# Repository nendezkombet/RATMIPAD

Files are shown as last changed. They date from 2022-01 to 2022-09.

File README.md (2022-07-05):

# RATMIPAD

Ratmi is multi layout macropad supports six analog potentiometer, two rotary encoders, 3.5mm TRS socket for sending out serial data like midi output and more. The firmware is fully QMK, see [build environment setup](https://docs.qmk.fm/#/getting_started_build_tools) then the [make instructions](https://docs.qmk.fm/#/getting_started_make_guide) for more information. 
The analog potentiometer outputs a midi signal which can be recognized by any software reads midi input. For hardware midi controller the PCB has 3.5mm TRS female socket footprint ( 3.5mm TRS male jack to 5-pin midi midi cable as connector required ), for this specific purpose the programaing code can be done with arduinoIDE.

Designer and maintainer: [sandipratama/nendezkombet](https://github.com/nendezkombet) 





## Table of contents

- [Features](#features)
- [Default Layout](#default-layout)
- [Optional Layout](#optional-layout)
- [PCB](#pcb)
- [BOM](#bom)
- [Case](#case)
- [Assembly Guide](#assembly-guide)
- [Firmware](#firmware)

## Features

- Cheap to build.
- Multi layout support.
- Easy to source components.
- Easy to build.
- Arduino Pro Micro 32u4 as MCU.
- RGB backlighting support (optional).
- Up to two rotary encoder support.
- Hardware midi controller support.
- Battery powered support ( as portable controller ).
- Completely open-source.

## Default Layout



## Optional Layout 



From left to right layout configuration :

1. 1x big encoder knob with 6x key switch.
2. 9x key switch.
3. 2x small encoder knob with 7x key switch.
4. 1x big encoder knob with 6x analog potentiometer.

## PCB

Top view

upper

Bottom view

bottom

## BOM

|Parts|Footprint|Quantity|
|:---|:---|:---|
|WS2812B RGB LED |5050|8|
|100nF capacitor|0805|8|
|Cherry MX style switch |3 or 5 pin|9|
|Rotary encoder|EC11|2|
|Arduino Promicro |32u4|1|
|10K pullup resistor (optional)|0805 or axial|9|
|220ohm resistor|0805 or axial|3|
|Reset button switch |6mm*2.5mm|1|
|B10K Analog potentiometer (optional) | RV09 or RK09|6|
|3.5mm TRS female socket (optional) |PJ313|1|
|Micro slide switch (optional)|MSS22D18 |1|
|9V battery (optional) ||1|
|8mm M2 "MALE TO FEMALE" brass standoff|round knurled|4|
|8mm M2 "FEMALE TO FEMALE" brass standoff|round knurled|4|
|6mm M2 screw|-|8|
|3.5mm TRS jack to 5-pin midi din male socket (optional) |see detail below|1|

51kXivjBTuL _AC_SX425_

you can build by your self, wiring instruction can by found in the google search engine.

## Case

Stacked acrylic case 





## Assembly Guide

See inside "case" folder !!!

## Firmware

Firmware flashing :

Open QMK Toolbox and locate The .hex file you compiled before or use ready flash default keymap

Enter the bootloader :

Briefly press the button twice on the small hole located in the top of the encoder with simcard ejector pin than hit flash

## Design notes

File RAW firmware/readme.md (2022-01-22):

RATMIPAD

Ratmi is multi layout macropad supports six analog potentiometer, two rotary encoders, 3.5mm TRS socket for sending out serial data like midi output and more. The firmware is fully QMK. The analog potentiometer outputs a midi signal which can be recognized by any software reads midi input. For hardware midi controller the PCB has 3.5mm TRS female socket footprint ( 3.5mm TRS male jack to 5-pin midi midi cable as connector required ), for this specific purpose the programaing code can be done with arduinoIDE.

* Keyboard Maintainer: [sandipratama/nendezkombet](https://github.com/nendezkombet)
* Hardware Availability: https://github.com/nendezkombet/ratmipad

Make example for this keyboard (after setting up your build environment):

    make ratmipad:default

See the [build environment setup](https://docs.qmk.fm/#/getting_started_build_tools) and the [make instructions](https://docs.qmk.fm/#/getting_started_make_guide) for more information. Brand new to QMK? Start with our [Complete Newbs Guide](https://docs.qmk.fm/#/newbs).

Bootloader
Enter the bootloader :

Physical reset button: Briefly press the button two times on the small hole in the top of the encoder with simcard ejector pin

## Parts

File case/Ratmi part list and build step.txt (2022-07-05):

Macropad purpose :

1. 8x WS2812B RGB LEDs ( optional )
2. 8x SMD 0805 100nF capacitors ( this part just for prevent noise/flicker )
3. 6-9x Cherry MX style switch or kailh low provile V2 switch 
4. 1-2x EC11 rotary encoder ( optional )
5. 8x 6mm height M2 female
6. 4x 8mm height M2 female to male brass standoff ( knurled and round shape, hex shape will not work )
7. 4x 8mm height M2 female to female brass standoff ( knurled and round shape, hex shape will not work )
8. 1x Arduino Promicro 32u4 5v
9. 1x 220ohm or 330ohm resistor for RGB data line
10. 1x micro switch for reset button

RATMI USED PIN LIST :

1. S1 switch (10) 
2. S2 switch (14) 
3. S3 switch (4) 
4. S4 switch (A1)
5. S5 switch (A0)
6. S6 switch (5)
7. S7 switch (9)
8. S8 switch (8)
9. S9 switch (6)
10.Encoder 1 (2, 3)
11.Encoder 2 (A3, A2)
12.RGB data line (7)

RATMI BUILD STEP :

Note : 
// Using solder flux very recomended !!!
// Prepare solder sucker if you make mistake
// Clip the leg of the component if it's to long
// Don't skip the build step

1. Solder 8 RGB led L1-L8 
2. Solder Capacitor C1-C8 
3. Solder resistor 220ohm/330ohm on R10 solder hole/pad ( for rgb leds data line )
4. Solder the encoder and reset switch
5. Solder arduino pin header ( just pin header, for arduino do it in the last step )
6. Attach all top plate on to PCB 
7. Lock with m2 screw and female standoff
8. Attach the switch buttons and tiddy up
9. Solder the switch 
10.Solder arduino to pin header
11.Attach and screw all bottom plate on to PCB 
13.Ready for firmware flashing

Other component like power slide switch , battery socket, trs female socket and battery just free to solder without follow the build step.
For midi connector cable wiring you can search on internet and make sure your wiring match with midi out on the PCB ex. TX-TX, VCC-VCC, and GND-GND

if you have any question and find some bugs please contact me @synthvestigator.gmail or comment in my youtube video for this project @synthvestigator

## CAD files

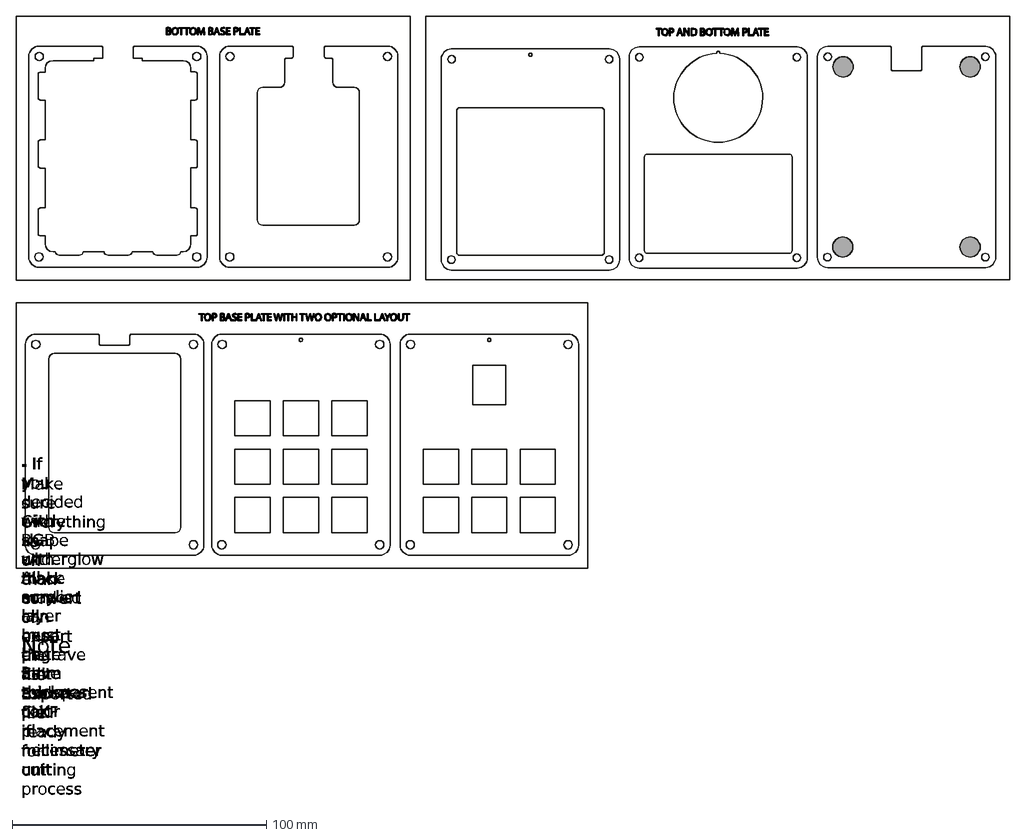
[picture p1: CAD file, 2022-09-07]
case/Ratmipad DXF cutting file.dxf
Note :
- All acrylic layer must be 3mm thicknes
- If you decided with RGB underglow make sure all base plate have transparent color
- Circle shape with black marked can be engrave for rubber pad placement
- Edit the file if necessary
- Make sure everything is ok than convert or export the file as .DXF in millimeter unit
- Exported file ready for cutting process

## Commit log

2022-01-22 Add cutting file
    case cutting file added
2022-01-23 Add gerber
    Lebeled V.1 if there any update in the future
2022-07-05 Gerber added
